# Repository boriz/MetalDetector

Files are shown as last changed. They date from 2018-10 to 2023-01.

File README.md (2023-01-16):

# MetalDetector
Simple Arduino-based metal detector.  
The antenna is 250mm x 70mm piece of cardboard with approximately 50 turns of 32AWG (0.2mm) wire. Measured antenna inductance is ~1mH.  

Schematic of the device is below:  

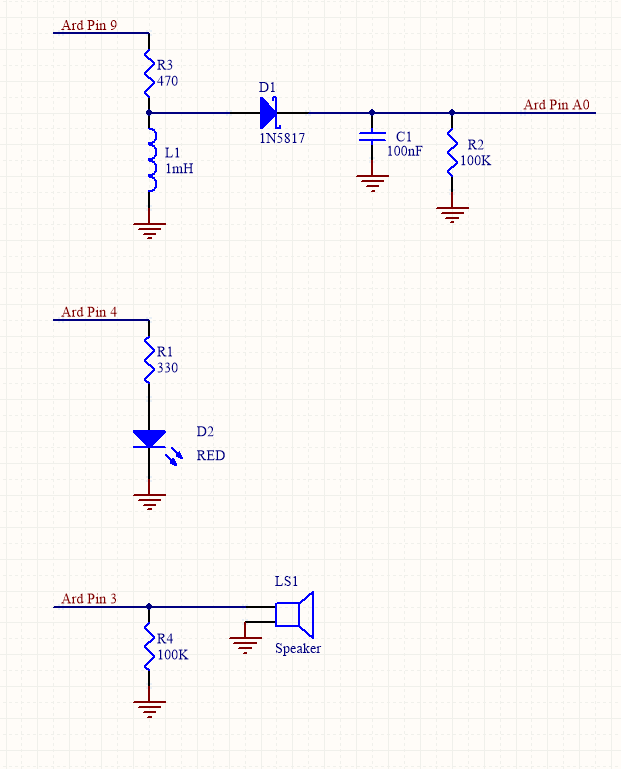
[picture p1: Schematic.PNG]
  

Arduino pin 9 is configured to output 20KHz (50us period) square wave, this AC voltage fed to top of the R3/L1 network.  
At 20KHz the reactance of the inductor is X = 2*pi*f*L1 = 125 Ohms. With R3 resistor, the L1 reactance forms an AC voltage divider.  
By placing a piece of metal near the inductor L1, we are changing its inductance/reactance, and consequently the output voltage of the divider.  
To measure the output voltage of the R3/L1 network, we rectify it with the diode D1 and filter with RC network C1/R2. The resulting DC voltage is sampled by the Arduino ADC (pin A0). This voltage is proportional to the inductance of the L1 and would change if we place a metal nearby.  
Arduino pin 4 is connected to an external LED.  
And pin 3 is connected to a piezo speaker.

Arduino code is very basic.  
Upon boot it samples ADC voltage and uses it as a staring point.  
It continuously samples ADC and if it drifts away from the starting point, the device beeps.
Note: Arduino code is using TimerOne library, you can install it via Sketch/Include Libraries menu.  

Pictures of the actual device are below.  

Coil, Main Board and Arduino Pro-Mini 
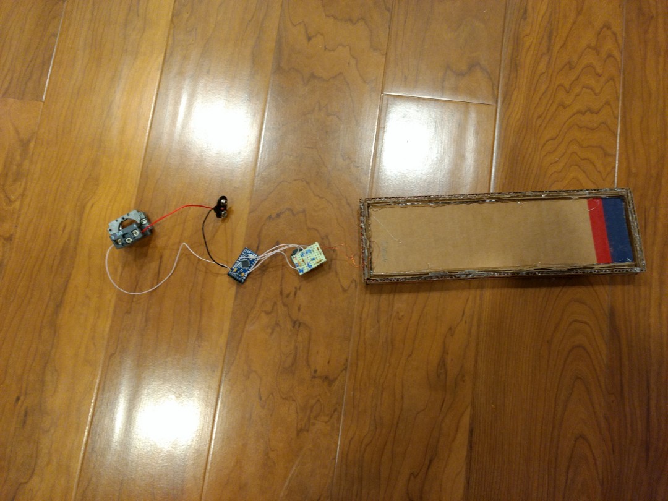
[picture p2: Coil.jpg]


Arduino and Main Board 
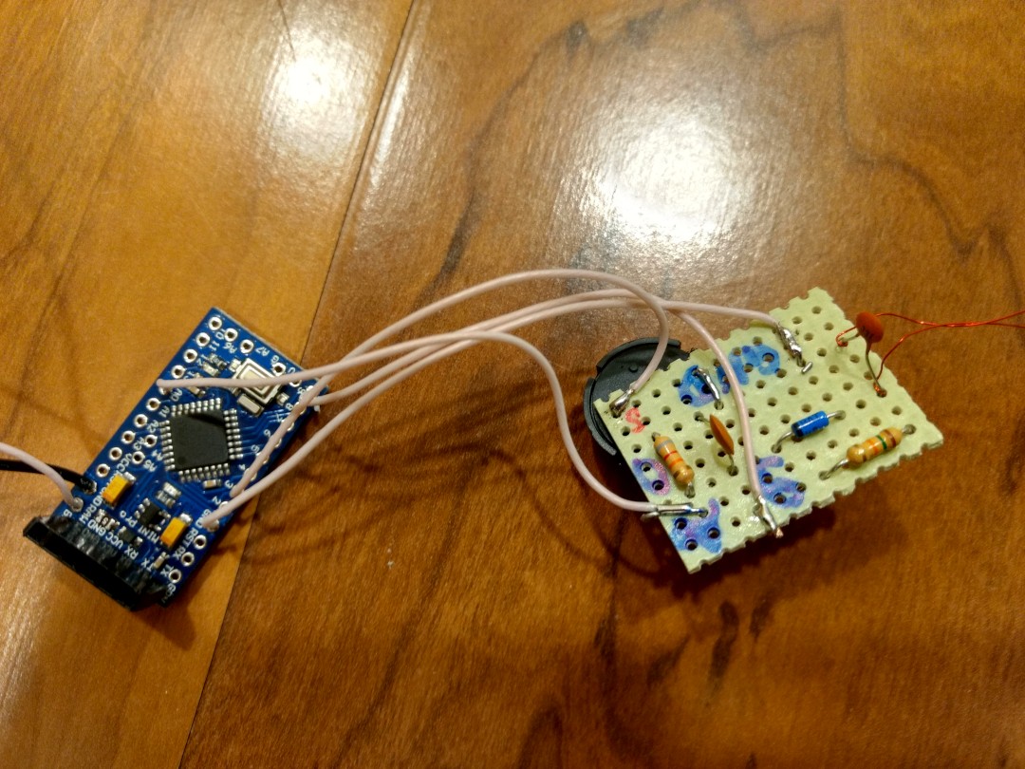
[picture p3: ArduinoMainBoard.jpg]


Assembled device (cardboard, hot glue and fancy power switch)
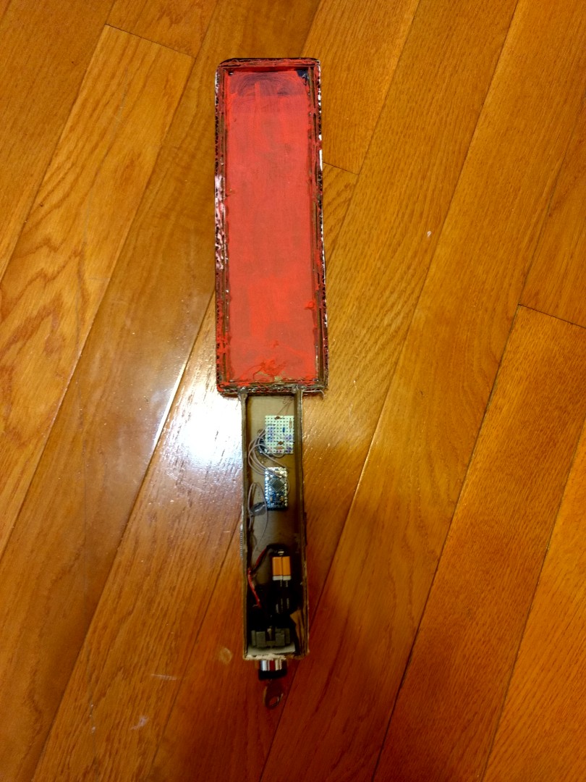
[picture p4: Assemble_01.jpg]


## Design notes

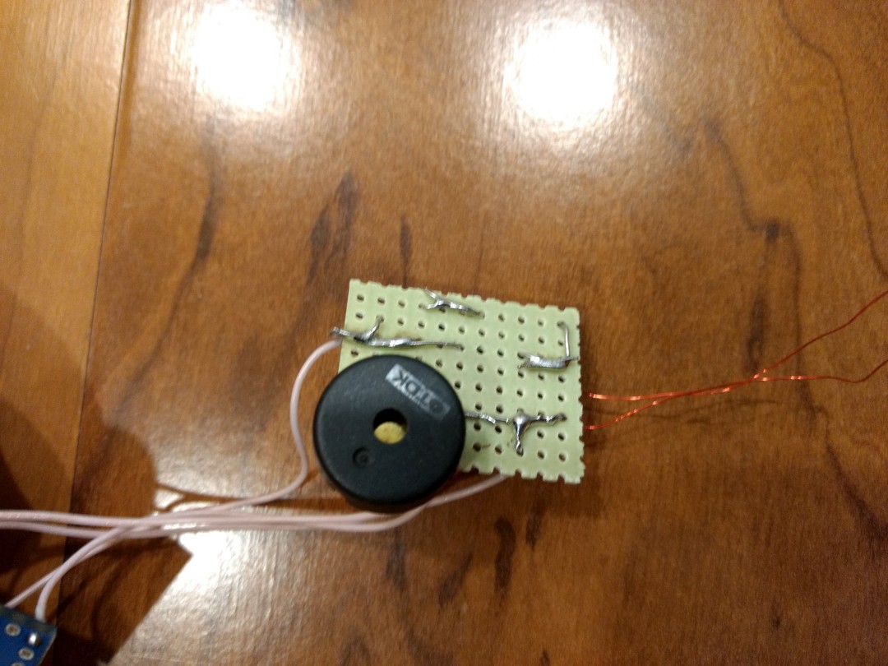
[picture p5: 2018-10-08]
ManiBoard.jpg

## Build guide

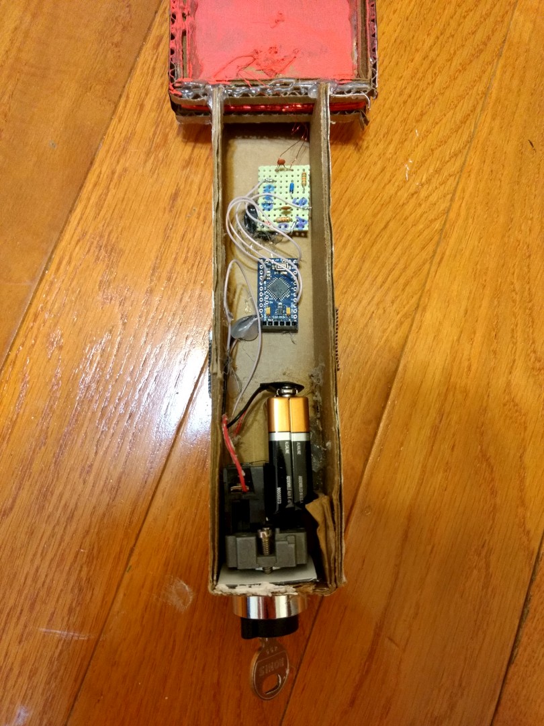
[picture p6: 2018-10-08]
Assembled02.jpg

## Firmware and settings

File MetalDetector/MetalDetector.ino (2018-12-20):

#include "TimerOne.h"

// Initialize global constants
const int TIMER_PERIOD_US = 50; // Frequency generator period in microseconds
const int GEN_PIN = 9;          // Frequency generator pin
const int LED_PIN = 4;          // LED pin
const int SPEAKER_PIN = 3;      // Speaker pin
const int SPEAKER_FREQ = 1000;  // Beep frequency
const int FB_PIN = A0;          // Analog feedback pin
const int THRESHOLD1 = 1;       // Slow beeep ADC/voltage threshold 
const int THRESHOLD2 = 2;       // Medium beep ADC/voltage threshold 
const int THRESHOLD3 = 4;       // Continous beep ADC/voltage threshold 
const int SERIAL_BAUD = 115200; // Serial port baudrate
const int AVG_COUNT = 200;      // How many times to read/average ADC voltage


// Global variables
int start_voltage;


// put your setup code here, to run once
void setup() 
{
  // Configure output pins
  pinMode(GEN_PIN, OUTPUT);
  pinMode(LED_PIN, OUTPUT);

  // Configure generator to selected frequency and 50% duty cycle
  Timer1.initialize(TIMER_PERIOD_US); 
  Timer1.pwm(GEN_PIN, 512);

  // Start serial output
  Serial.begin(SERIAL_BAUD);

  // Wait for voltage to stabilize
  delay(100); 

  // beep to indicate that we are on
  digitalWrite(LED_PIN, HIGH);
  tone(SPEAKER_PIN, SPEAKER_FREQ, 3000);
  delay(2000);
  digitalWrite(LED_PIN, LOW);
      
  // Calibrate voltage
  delay(100);
  start_voltage = ReadVoltage();
}


// Main functionality
void loop() 
{
  // Reads current voltage level
  int read_voltage = ReadVoltage();
  
  // Compare to the start voltage
  int difference = abs(read_voltage - start_voltage);
  
  // print it if above minimum threshold
  if (difference> THRESHOLD1)
  {
    Serial.print("start "); 
    Serial.print(start_voltage);
    Serial.print(" read ");  
    Serial.print(read_voltage);
    Serial.print(" difference ");  
    Serial.println(difference); 
  }

  // beep based on difference
  if (difference > THRESHOLD3)
  {
    // continous beep
    digitalWrite(LED_PIN, HIGH);
    tone(SPEAKER_PIN,SPEAKER_FREQ, 100);
  }
  else if (difference > THRESHOLD2)
  {
    // medium beep
    digitalWrite(LED_PIN, HIGH);
    tone(SPEAKER_PIN, SPEAKER_FREQ, 50);
    delay(50);
    digitalWrite(LED_PIN, LOW);
    delay(50);    
  }  
  else if (difference > THRESHOLD1)
  {
    // light beep
    digitalWrite(LED_PIN, HIGH);
    tone(SPEAKER_PIN, SPEAKER_FREQ, 20);
    delay(20);
    digitalWrite(LED_PIN, LOW);
    delay(180);    
  }
  else 
  {
    // Pull LED off if no metal is dtected
    digitalWrite(LED_PIN, LOW);
  }
}


// Read voltage from analog pin A0 and heavy average it
int ReadVoltage()
{
  long sum;
  sum = 0;
  
  for (int i=0; i < AVG_COUNT; i++)
  {
    sum = sum + analogRead(FB_PIN);
  }
  return sum / AVG_COUNT;
}

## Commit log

2018-10-05 Tested on Arduino Pro Micro.
2018-10-05 Update README.md
    Update readme and add schematic.
2018-12-20 Cleaned-up Arduino code. Updated description and schematic.
    [Schematic.SchDoc]
